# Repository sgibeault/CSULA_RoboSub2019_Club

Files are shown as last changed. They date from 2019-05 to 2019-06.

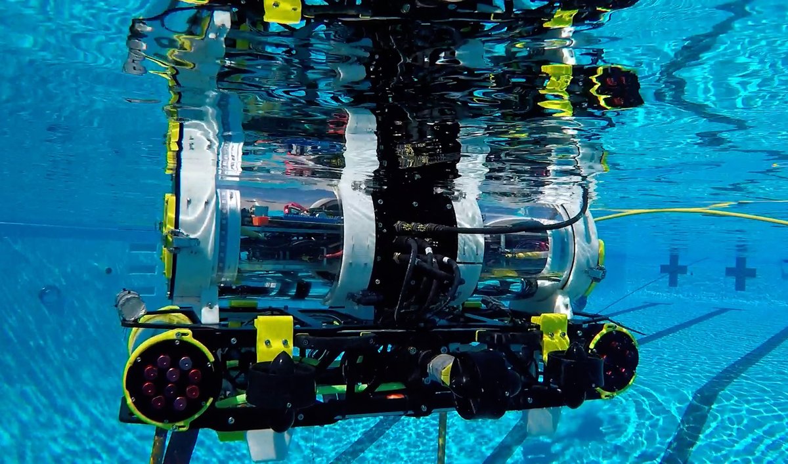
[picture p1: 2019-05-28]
Administrative_Stuff/Photos_Videos/SubPhoto.jpg

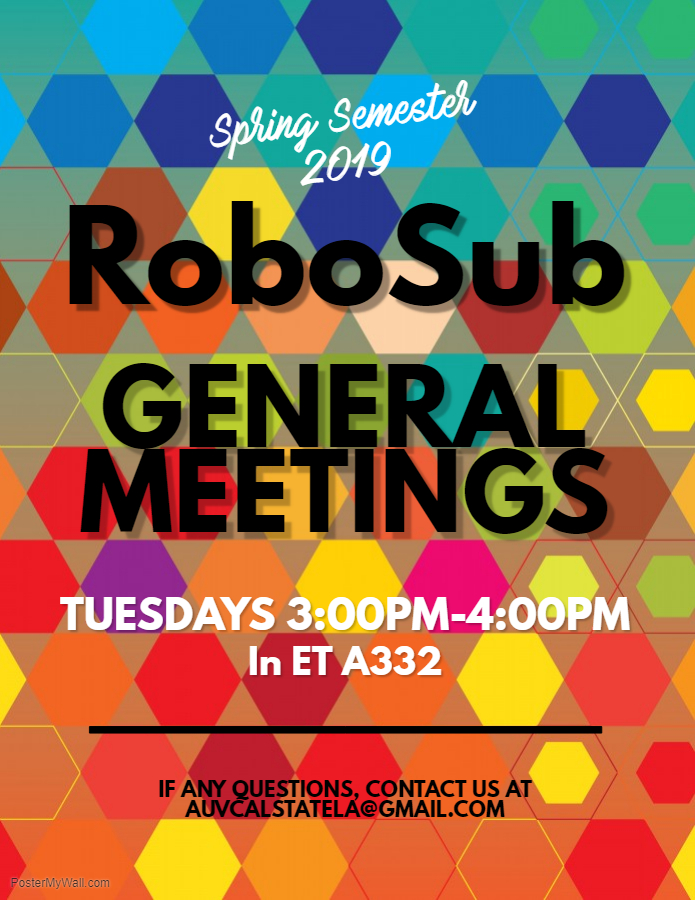
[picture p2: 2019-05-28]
Administrative_Stuff/New_Members/General_Meeting_Stuff/Spring2019GenMeetingFlyer.png

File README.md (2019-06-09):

# CSULA_RoboSub2019_Club
Files for the CSULA RoboSub 2019 club submarine. Her name is M4G1K4RP. 

Sidra's tasks for this week (6/10/19):
- Test barometer in yellow tub in the lab (Tuesday)
- Solder battery connectors and see if we could use the longer tether for next testing (Tuesday)
- Fix library errors with uploading Arduino code over SSH, test this with motherboard on sub (Tuesday)
- Test cameras with CV alg (Wednesday)
- Start working with CV algorithm, set up a plan for training CV -- this means all ROS interfacing between the navigation system and computer vision system should be planned out (Wednesday)
- Install a camera temporarily (Friday)
- Test primitive interface, get a CV system that functions -- doesn't have to detect anything perfectly, just try to get something that works (Friday)

Joseph/Alfonso's tasks for this week (6/10/19):
- Shelving unit laser cut and installed (by Saturday)
- Thruster mounts (by Saturday)

**We will decide on Saturday what the next tasks will be**

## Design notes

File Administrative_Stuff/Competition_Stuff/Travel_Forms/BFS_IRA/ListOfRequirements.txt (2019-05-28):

At Least 14 Days Before:
- Request for Travel
- Breakdown of Expenses
- Class release
- General release for each member
- Emergency contact info for each member
- Lodging exception form 
  + reason why we chose the hotel if over 275/night
- Additional documents/brochure/info
- Fill out this thing: https://na2.docusign.net/Member/PowerFormSigning.aspx?PowerFormId=4b7340e0-2e3a-49a3-bc6e-6d9e34c49fc2

After: 
- Travel expense claim

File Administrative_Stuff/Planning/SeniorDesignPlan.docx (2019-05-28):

# ME RoboSub Senior Design Schedule

Goals

The main goals for the 2019 RoboSub project are to reduce the weight and size of the sub’s frame and reduce the amount of space taken up by the electronics system. Last year’s project will be used as a reference for these tasks. The weight of last year’s submarine is 98lbs, and we hope to reduce this to less than 85lbs. For the electronics system, we want a custom made dc-dc converter circuit board that has multiple voltage outputs, a custom servo control board, and a hydrophone control board. We hope that everyone will be dedicated to the project and will choose to attend the competition with the team next July!

Fall Semester

Week 3 (Sep 2-8) Learn about the project

Week 4 (Sep 9-15) Learn about the project

Week 5 (Sep 16-22) Plan frame/hull weight reduction, review old circuit boards and electrical interface

Week 6 (Sep 23-29) Plan frame/hull weight reduction, research sensors

Week 7 (Sep 30-Oct 6) Plan frame/hull weight reduction, work on power distribution board schematic

Week 8 (Oct 7-13) Begin SolidWorks sub model, work on power distribution board schematic

Week 9 (Oct 14-20) SolidWorks sub design, power distribution board CAD/breadboard testing

Week 10 (Oct 21-27) SolidWorks sub design, work on servo board schematic

Week 11 (Oct 28-Nov 3) SolidWorks sub design, work on servo board schematic

Week 12 (Nov 4-10) Finish sub CAD model, servo board CAD/breadboard testing

Week 13 (Nov 11-17) Buy materials, research manufacturing costs, research electronic components/prices

Week 14 (Nov 25-Dec 1) Send out parts to be manufactured, order boards and components

Week 15 (Dec 2-8) Study :)

Spring Semester

Week 1 (Jan 20-26) Weight calculations

Week 2 (Jan 27-Feb 2) Weight calculations

Week 3 (Feb 3-9) Assembly

Week 4 (Feb 10-16) Assembly

Week 5 (Feb 17-23) Component placement

Week 6 (Feb 24-Mar 2) Component placement

Week 7 (Mar 3-9) Documentation

Week 8 (Mar 10-16) Adjustments

Week 9 (Mar 17-23) Adjustments

Week 10 (Mar 24-30) Adjustments

Week 11 (Apr 7-13) Buoyancy testing/adjusting

Week 12 (Apr 14-20) Buoyancy testing/adjusting

Week 13 (Apr 21-27) Pool testing

Week 14 (Apr 28-May 4) Pool testing

Week 15 (May 5-11) Study :)

Spring Semester

Week 1 (Jan 20-26) Wire thickness calculations

Week 2 (Jan 27-Feb 2) Hydrophone board schematic

Week 3 (Feb 3-9) Hydrophone board schematic

Week 4 (Feb 10-16) Hydrophone board CAD/breadboard testing

Week 5 (Feb 17-23) Order hydrophone board & components, soldering

Week 6 (Feb 24-Mar 2) Soldering components

Week 7 (Mar 3-9) Wiring the electrical interface

Week 8 (Mar 10-16) Wiring the electrical interface

Week 9 (Mar 17-23) Waterproofing

Week 10 (Mar 24-30) Waterproofing

Week 11 (Apr 7-13) Connectors

Week 12 (Apr 14-20) Connectors

Week 13 (Apr 21-27) Pool testing

Week 14 (Apr 28-May 4) Pool testing

Week 15 (May 5-11) Study :)

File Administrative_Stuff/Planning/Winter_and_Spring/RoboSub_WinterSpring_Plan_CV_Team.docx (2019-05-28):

# Computer Vision Team Schedule

Goals

The goal of the computer vision team is to create a system using ROS and OpenCV that can detect objects and colors under the water using a camera module, go pro, or webcam (whichever is easiest). This system will provide the signals to the Arduino controlling the thruster movement and navigation.

Winter

Week 1 (Dec 17-23) Finish learning about ROS, practice programming packages, nodes, messages, services etc. Create architecture.

Week 2 (Dec 24-30) Work on CV system programming, learn how to use OpenCV. Research options, finalize architecture

Week 3 (Dec 31-Jan 6) Work on programming

Week 4 (Jan 7-13) Work on programming

Week 5 (Jan 14-20) Work on programming

Spring

Week 1 (Jan 21-27) Test system with simple object detection, make changes as needed

Week 2 (Jan 28-Feb 3) Continue testing and bug fixing

Week 3 (Feb 4-10) CV system ready for pool testing.

Week 4 (Feb 11-17) Work on interfacing navigation system

Week 5 (Feb 18-24) Have a test-ready vehicle (assemble everything)

Week 6 (Feb 25-Mar 3) Finish interfacing navigation system

Week 7 (Mar 4-10) Second pool test: image collecting

Week 8 (Mar 11-17) Third pool test: image collecting

Week 9 (Mar 18-24) Fourth pool test: image collecting and CV testing

Week 10 (Mar 25-31) Fifth pool test: image collecting and CV testing

Spring Break (Apr 1-7) Finish CV integration with weapons systems. Sixth pool test: weapons systems

Week 11 (Apr 8-14) Testing

Week 12 (Apr 15-21) Testing

Week 13 (Apr 22-28) Testing

Week 14 (Apr 29-May 5) Testing

Week 15 (May 6-12) Testing

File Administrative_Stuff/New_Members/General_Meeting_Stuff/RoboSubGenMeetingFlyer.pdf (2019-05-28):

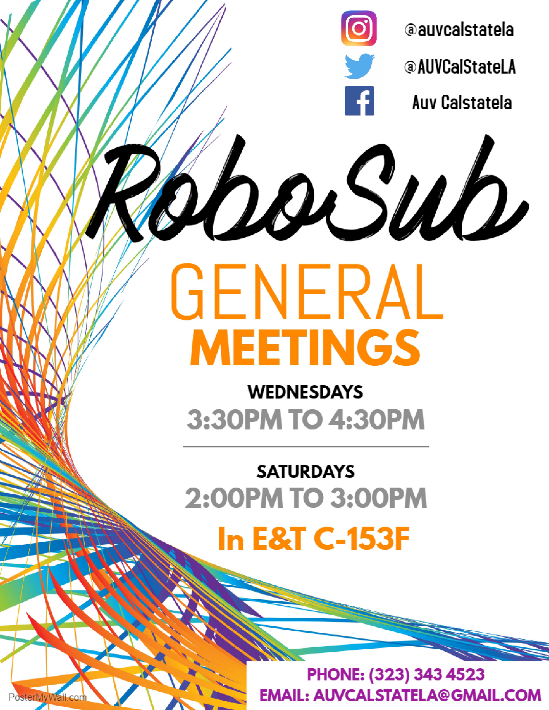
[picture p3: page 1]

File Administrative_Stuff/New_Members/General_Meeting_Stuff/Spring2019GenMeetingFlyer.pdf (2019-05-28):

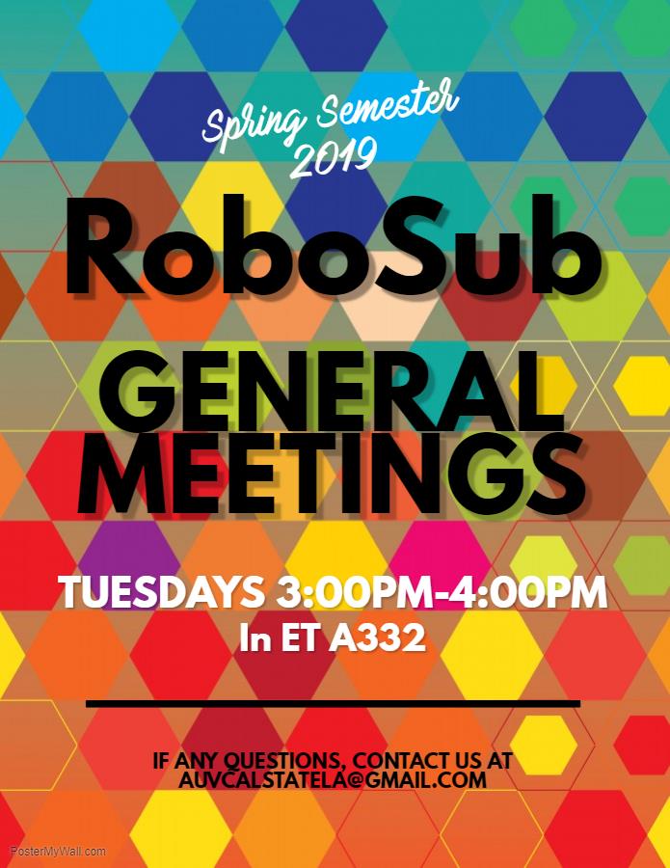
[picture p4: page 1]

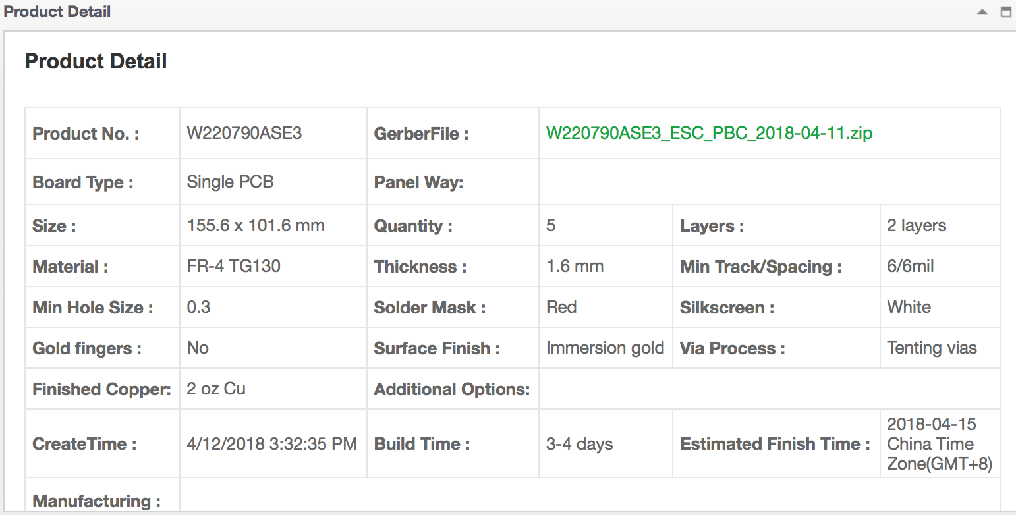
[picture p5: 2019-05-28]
Electrical/EagleCAD_Thruster_Board/Screen Shot 2018-04-15 at 4.21.25 PM.png

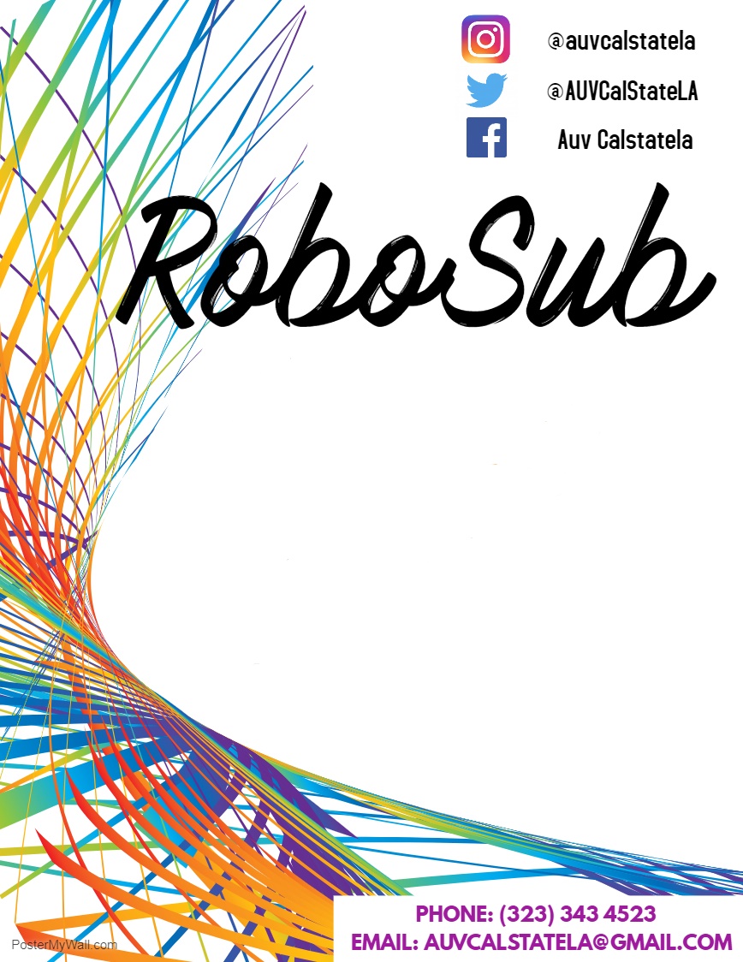
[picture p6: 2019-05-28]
Administrative_Stuff/New_Members/General_Meeting_Stuff/InkedRoboSubBlankFlyer.jpg

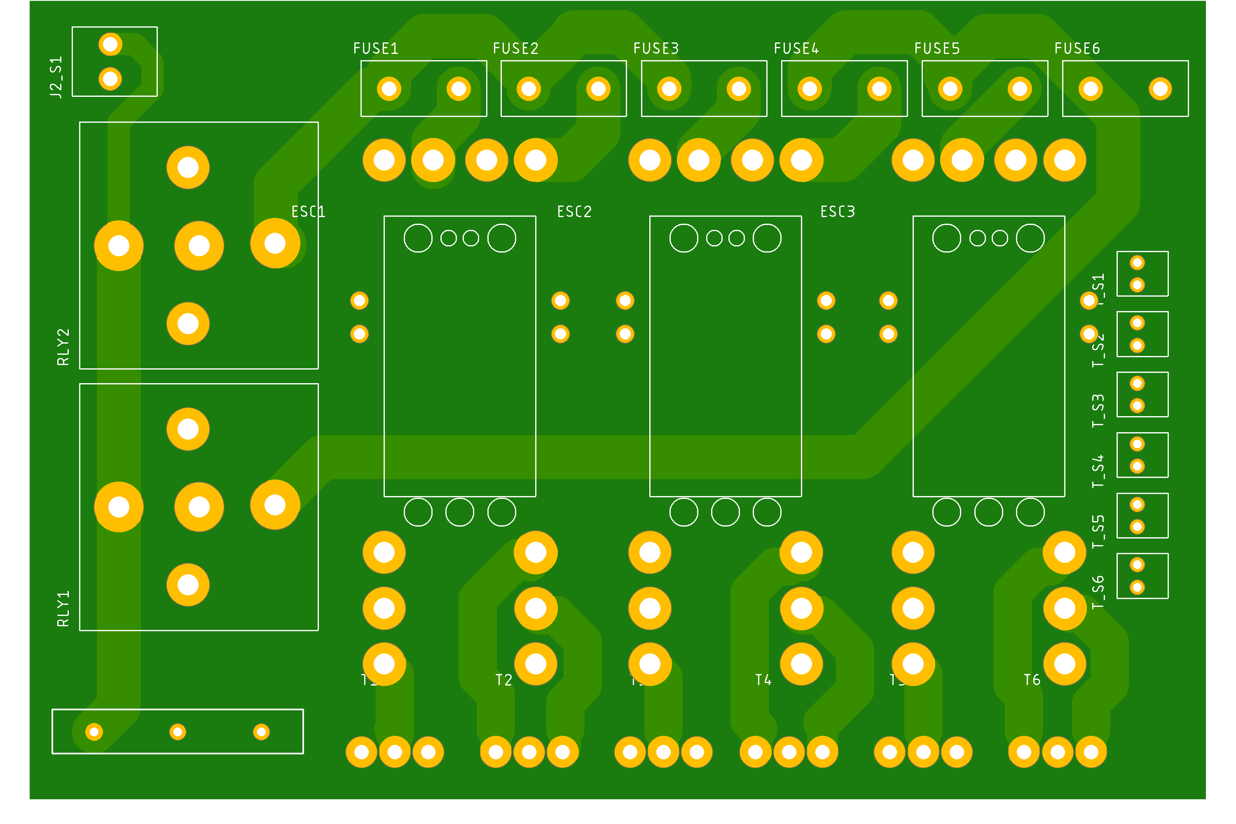
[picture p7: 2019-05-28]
Electrical/EagleCAD_Thruster_Board/TBoard_2019.png

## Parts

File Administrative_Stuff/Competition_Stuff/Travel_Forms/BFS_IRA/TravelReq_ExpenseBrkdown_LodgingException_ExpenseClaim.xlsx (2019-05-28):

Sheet: Breakdown of Expenses
 | Dates | Dates | Dates | Dates | Dates
Description |  |  |  |  |  | Total
Registration/business expense | $0.00 | $0.00 | $0.00 | $0.00 | $0.00 | $0.00
Hotel/lodging (Max. $275.00 before taxes) | $0.00 | $0.00 | $0.00 | $0.00 | $0.00 | $0.00
Airfare/transportation | $0.00 | $0.00 | $0.00 | $0.00 | $0.00 | $0.00
Meals up to $55.00 with overnight stay | $0.00 | $0.00 | $0.00 | $0.00 | $0.00 | $0.00
Incidentals (up to $7.00) | $0.00 | $0.00 | $0.00 | $0.00 | $0.00 | $0.00
Mileage (54.5 cents per mile) | $20.00 | $0.00 | $0.00 | $0.00 | $0.00 | $20.00
Rental Car/Taxi/Shuttle/transportation | $0.00 | $0.00 | $0.00 | $0.00 | $0.00 | $0.00
Gas/business expense | $0.00 | $0.00 | $0.00 | $0.00 | $0.00 | $0.00
Phone/Fax/business expense | $0.00 | $0.00 | $0.00 | $0.00 | $0.00 | $0.00
Parking | $0.00 | $0.00 | $0.00 | $0.00 | $0.00 | $0.00
Relocation/Moving Expense | $0.00 | $0.00 | $0.00 | $0.00 | $0.00 | $0.00
 | $20.00 | $0.00 | $0.00 | $0.00 | $0.00 | $20.00
Traveler:
Purpose:
Shuttle:

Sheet: Travel Form
 | Business Financial Services
Request for Travel
I. GENERAL INFORMATION: |  |  |  |  | SHADED AREAS FOR ACCOUNTING USE ONLY
Last Name, First Name |  |  |  |  |  | Initials |  | Employee ID#
Department |  |  |  |  | Ext. | Destination of Trip (City\State\Country (Intl Travel)
Departure to Destination |  |  | Date | Time |  | Return from |  | Date |  | Time
 |  |  |  |  |  | Destination
 | Emergency Contact |  | ___________________________________________________________________
Emergency Phone Number/Email |  |  | ___________________________________________________________________
Home/Remit Address
Personnel Classification/Type of Travel (Check one box in each column):
 | Employee Category |  |  |  |  | Type of Travel |  |  |  |  |  | 606802 Travel - Mileage
 |  | A |  |  |  | A |  |  |  |  |  | 606802 Travel - Mileage
 |  | B |  |  |  | B
 |  | C |  |  |  | C
 |  | D |  |  |  | D
 |  | E |  |  |  | E
 |  | F |  |  |  | F |  |  |  |  |  | 606800 Travel - in State
 |  |  |  |  |  | G
 |  |  |  |  |  |  |  |  |  |  |  | 606801 Travel - in State Faculty
II. FINANCIAL INFORMATION |  |  |  |  |  |  |  |  |  |  |  | 606820 Travel - out of State
Account |  |  | Fund-Department-Program-Project |  |  |  |  | Amount |  |  |  | 606821 Travel - out of State Faculty
 |  |  |  |  |  |  |  | $0.00 |  |  |  | 660890 Recruitment and Emp Relocation
 |  |  |  |  |  |  |  | $20.00 |  |  |  | 660891 Faculty Recruitment
 |  |  |  |  |  |  |  | $0.00 |  |  |  | 660977 Official Guest
 |  |  |  |  |  |  |  | $0.00 |  |  |  | 613001 Contractual services
 |  |  |  |  |  |  |  | $20.00 | ** Total Request |  |  | 660850 Guest artists
 |  |  |  |  |  |  |  |  |  |  |  | 606807 Travel Overtime meal Reimb
 | ** Total Request should include all expenses. In the event expenses are more than original request, please |  |  |  |  |  |  |  |  |  |  | 606806 Team Travel - in State
 | submit a memo from department to increase amount along with travel claim. |  |  |  |  |  |  |  |  |  |  | 606811 Team Travel - out of State
 |  |  |  |  |  |  |  |  |  |  |  | 660972 Honorarium
Signature of Traveling Requestor |  |  |  |  | Date |  | Signature of Authorized Personnel |  |  |  | Date | 660009 Specialized Training
International Approval: |  |  |  |  |  |  |  |  |  |  |  | 606802 Travel - Mileage
Vice President |  |  |  |  | Date |  | President |  |  |  | Date | 606803 Travel - Mileage Faculty
Per Administrative Procedure 208, approval is required when reimbursement for moving and relocation expenses exceeds $5,000/$10,000.
Vice President |  |  |  |  | Date |  | Vice President for Administration and CFO |  |  |  | Date | 606803 Travel - Mileage Faculty
III. REQUEST FOR TRAVEL ADVANCE
TO: | Business Financial Services: Please issue me a travel advance check in the amount of :
 | Name of Company |  |  |  | Amount | for the above trip. |  |  |  | Date
 |  |  |  |  |  | I need the advance by:
 | Authorization by Employee: |  |  |  | This is to authorize the University to deduct from my paycheck any
 |  |  |  |  | outstanding travel advance after 30 calendar days from return of trip.
 |  |  |  |  |  | Signature of Employee Requesting Advance
 | Date:
 | Form Prepared By:
 |  |  |  |  | Purpose of Trip:
Forms Required:
Form 204 |  |  |  | Remarks:
Breakdown of Expenses
Form 262
Form 261 |  |  |  | Advance Check |  | Number |  |  | Date |  | $ Amount
____________ Other |  | Revised: January 2016 |  | Information

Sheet: Travel Check List
Request for Travel – Advances (submit copy to Business Financial Services)
Checklist Items | Yes | Not Required | Comments | BFS use only
Breakdown of Expenses Spreadsheet
Supporting Documents - Agenda, Brochure, Invitation
Invoice/Confirmation for Hotel, Registration, Airfare and/or Car Rental (requires 204 form if new vendor)
Receipt for Prepaid Expense
CPO (cash posting order) Memo/Registration
International with Advance
International Travel – Provost and President approval
High Hazard Questionnaire (if applicable)
Request for Travel – Moving & Relocation (submit copy to Business Financial Services)
Dates of the Move
Approval
* Dean ‘s approval for $5k or less
* Vice President’s approval for less than $10k
* VPAF/CFO’s approval for $10k and over
Moving Company Estimate, 204 form, Certification of Insurance (if applicable)
Request for Travel – Off Campus Event (submit copy to Business Financial Services)
Waiver from Golden Eagle
Certificate of Insurance for Venue
Agreement |  |  | Approved by Procurement only
Invoice/Estimate
Hospitality Form
Travel Expense Claim (include the original Request for Travel)
Checklist Items | Yes | Not Required | Comments | BFS use only
Written on Claim
Time of Departure and Return
Purpose of Trip
Work Hours
Private Vehicle License Number
Supporting Documentation
Agenda, Brochure, Invitation
Transportation receipt (air, rental, taxi, bus, shuttle)
Lodging Receipt
Lodging Exception (Approved prior to trip)
Registration Receipt
Parking Expense Receipt
Map/Proof of Mileage
Receipts for any expenses $25.00 and over
Approval signature for claim reimbursement that is over the Request for Travel amount
Form 261 (Authorization to Use Privately Owned Vehicle on State Business) |  |  | Attach if not previously submitted for the current fiscal year
Group Meals - Hospitality Form & List of Participants
Moving & Relocation – Receipts for out of pocket expenses
Revised: November 7, 2014

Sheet: Travel Claim
State of California
TRAVEL EXPENSE CLAIM |  |  |  | See Instructions and "Privacy
STD. 262 (REV. 6/93) |  |  |  | Statement On Reverse Side |  |  |  |  |  |  | Page ________ of _______Pages
CLAIMANT'S NAME |  |  |  |  |  |  |  |  |  |  | DEPARTMENT
POSITION |  |  |  | CB/ID NUMBER |  | DIVISION OR BUREAU |  |  |  |  |  |  | I NDEX NUMBER
 |  |  |  |  |  | CSU Los Angeles
RESIDENCE ADDRESS* |  |  |  |  |  | HEADQUARTERS ADDRESS |  |  |  |  |  |  | TELEPHONE NUMBER
 |  |  |  |  |  | 5151 STATE UNIVERSITY DRIVE
CITY |  |  | STATE | ZIP CODE |  | CITY |  |  |  |  | STATE |  |  | ZIP CODE
 |  |  |  |  |  | LOS ANGELES |  |  |  |  | CA |  |  | 90032
(1) MONTH/YEAR |  | (3) | (4) | (5) | MEALS |  | (6) | (7) |  | TRANSPORTATION |  |  | (8) | (9)
 |  |  |  |  |  | O.T.. L/T |  | (A) | (B) | (C) |  | (D)
 |  | LOCATION |  |  |  | N/C, RELOC. | INCIDEN- |  |  | CARFARE, | PRIVATE CAR USE |  | BUSINESS | TOTAL
(2) |  | WHERE EXPENSES | LODGING | BREAK- |  | OR | TALS | COST OF | TYPE | TOLLS, |  |  | EXPENSE | EXPENSES
DATE | TIME | WERE INCURRED |  | FAST | LUNCH | DINNER |  | TRANS. | USED | PARKING | MILES | AMOUNT |  | FOR DAY
 |  |  |  |  |  |  |  |  |  |  |  |  |  | 0.00
 |  |  |  |  |  |  |  |  |  |  |  |  |  | 0.00
 |  |  |  |  |  |  |  |  |  |  |  |  |  | 0.00
 |  |  |  |  |  |  |  |  |  |  |  |  |  | 0.00
 |  |  |  |  |  |  |  |  |  |  |  |  |  | 0.00
 |  |  |  |  |  |  |  |  |  |  |  |  |  | 0.00
 |  |  |  |  |  |  |  |  |  |  |  |  |  | 0.00
 |  |  |  |  |  |  |  |  |  |  |  |  |  | 0.00
 |  |  |  |  |  |  |  |  |  |  |  |  |  | 0.00
 |  |  |  |  |  |  |  |  |  |  |  |  |  | 0.00
 |  |  |  |  |  |  |  |  |  |  |  |  |  | 0.00
 |  |  |  |  |  |  |  |  |  |  |  |  | CT
 |  |  |  |  |  |  |  |  |  |  |  |  | Advances
 |  |  |  |  |  |  |  |  |  |  |  |  | Bal. | 0.00
(10)
 | SUBTOTALS |  | 0.00 | 0.00 | 0.00 | 0.00 | 0.00 | 0.00 |  | 0.00 |  | 0.00 | 0.00 | 0.00
COLUMNS CODE (ACCTG. USE ONLY)
 | CLAIM TOTAL |  |  |  |  |  |  |  |  |  |  |  | $ | 0.00
(11) PURPOSE OF TRIP, REMARKS AND DETAILS (Attach Receipts/vouchers when required) |  |  |  |  |  |  |  |  |  |  |  | (12) NORMAL WORK HOURS
 |  |  |  |  |  |  |  |  |  |  |  | (13) PRIVATE VEHICLE LICENSE NUMBER
Advances:
 |  |  |  |  |  |  |  |  |  |  |  | (14) MILEAGE RATE CLAIMED
 |  |  |  |  |  |  |  |  |  |  |  |  | 54.5
Please reimburse actual expenses; instead of amount on Request. ________________________________________________ |  |  |  |  |  |  |  |  |  |  |  | AGENCYACCOUNTING OFFICE
AB 1887 Travel Exemption (submit justification) |  |  |  |  |  |  |  |  |  |  |  | USE ONLY
 | Account Number: |  |  |  |  |  |  |  |  |  |  | PAID BY REVOLVING FUND CHECK NUMBER
(15) | I HEREBY CERTIFY That the above is a true statement of the travel expenses incurred by me in accordance with DPA rules in the service of the State
 | of California. If a privately owned vehicle was used, and if mileage rates exceed the minimum rate, I certify that the cost of operating the vehicle was equal
 | to or greater than the rate claimed, and that I have met the requirements as presceibed by SAM Sections 0750, 0751, 0752, 0753 and 0754 pertaining to
 | vehicle safety and seat belt usage.
CLAIMANT'S SIGNATURE |  |  |  | DATE |  | (16) SIGNATURE OF OFFICER APPROVING TRAVEL AND PAYMENT |  |  |  |  |  |  | DATE
(17) SPECIAL EXPENSE AUTHORIZATION - SIGNATURE and TITLE (See Item 17on Reverse) |  |  |  |  |  |  |  |  |  |  |  |  | DATE

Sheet: Intl High Hazard
TRAVELER'S INFORMATION FOR HIGH HAZARD AREAS/COUNTRIES
Last Name, First Name |  |  | Employee Type:
*If traveler is a student, was an Informed Consent/Waiver executed? (YES/NO)
**If traveler is a minor, was an Informed Consent/Waiver executed by a parent or guardian? (YES/NO)
Is This Trip Sponsored by the University? (YES/NO)
Destination Information (Include all Regions, Cities and Towns) |  |  |  |  | From | To
Do any of your destinations (including layovers) appear on the following lists? (YES/NO)
1. High Hazardous (http://www.calstate.edu/risk_management/documents/CSURMA_HighHazardList.pdf)
2 US State Department Travel Warning (http://www.travel.state.gov)
If less than 5 days’ notice, provide reason for late request below:
Purpose Of Travel: |  | *Other (describe):
Value to campus or CSU as it relates to University business:
For Group Trips, please list ALL travelers:
Campus Coordinator Name:
Campus Coordinator Phone:
Employee Traveling? (YES/NO) |  |  | If YES, then please list names below:
Employee Name: |  | Employee Name:
Employee Name: |  | Employee Name:
Student Traveling? (YES/NO) |  |  | Total # of Students Traveling:
Student Name: |  | Student Name:
Student Name: |  | Student Name:
Other Participants? (YES/NO) |  |  | If YES, then please list names below:
Participant Name: |  | Participant Name:
Participant Name: |  | Participant Name:
TRANSPORTATION TO/FROM THE FOREIGN DESTINATION:
Airports being used: List All Airports
Transportation To/From the Foreign Destination (check all that apply):
Air | Rental Car |  | Bus |  | Other*:
Motor Vehicle | Hired Car |  | *If Other (please specify below):
Ship/Boat | Hired Driver
Contact Information While on Travel
Traveler Phone #: |  |  | Type:
Emergency Contact:
Emergency Contact Phone: |  |  | Contact Relationship:
LODING WHILE ON TRAVEL (provide information for all lodging locations):
Lodging Name:
Lodging Address:
Lodging Phone:
Lodging Name:
Lodging Address:
Lodging Phone:
SITE VISIT DETAILS |  |  |  | Type:
Site Location:
Site Point of Contact:
TRANSPORTATION TO/FROM LODGING AND SITE LOCATION
Airports being used: List All Airports
Transportation To/From Lodging and Site Location (check all that apply):
Air | Rental Car |  | Bus |  | Other*:
Motor Vehicle | Hired Car |  | *If Other (please specify below):
Ship/Boat | Hired Driver
Traveler Enrolled in US State Department STEP? (Safe Traveler Enrollment Program)
Additional Security Concerns?

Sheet: Lodging Exception
 |  | Request for Exception Lodging (maximum $275.00 per night)
 |  | TRAVEL – Business Financial Services
 |  | Administration 514 * (323) 343-3550
Date: |  |  |  | Department: |  |  | Extension:
Traveler’s Information:
Last Name: |  |  |  |  |  | First Name:
Destination of Trip: |  |  |  |  |  | Daily Rate (Before Taxes):
Departure Date: |  |  |  |  |  | Return Date:
Justification for Exception:
Vice President Exception Approval:
Print Name |  |  |  |  | Signature |  |  | Date
VPA & CFO Review and Recommendation
Approved | o | Denied | o |  | Signature: |  |  | Date:
 |  |  |  |  | Lisa Chavez, VPA & CFO, Administration & Finance
FOR TRAVEL DEPARTMENT ONLY:

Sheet: Routing Forms
 | TRAVEL – Business Financial Services
Submission of Forms
Prior to Trip:
Request for Travel Form and the Breakdown of Expenses Spreadsheet to Business Financial Services
a. Submit the approved Request for Travel and Breakdown of Expenses (Advances - two weeks prior to trip)
b. International Travel: submit approved Request for Travel and Breakdown of Exenses two months prior to trip
Advances consist of: Registration Fees, Prepaid Expenses, Airfare, Hotel, CPO (Cash Posting Order) and Rental Car.
International Travel Questionnaire for High Hazard Area
a. Complete form and send it along with a copy the approved Request for Travel and Breakdown of Expenses Spreadsheet
b. Dean's Office will forward the form to the Provost for approval
c. Provost Office will forward form to the President's Office
d. President's Office will return form to the Provost Office
Lodging Exception for $195.00 maximum excluding taxes
a. Complete form and send it along with a copy of the approved Request for Travel and Breakdown of Expenses Spreadsheet
b. Vice President Office needs to forward the form to Lisa Chavez for authorization
c. VPA & CFO will forward the form to Business Financial Services
Trip Completed:
Travel Expense Claim
a. Must be submitted to the campus Business Financial services office within 30 days of the end of the trip.
b. Original Request for Travel Form
c. Receipts and supporting documentation
d. Travel Check List

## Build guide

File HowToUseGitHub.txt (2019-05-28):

/* 
 * This document was written by Sidra Gibeault
 * Last updated on 5/28/19
 * This file is property of the CSULA RoboSub team
*/

Hi fellow CalStateLA AUV members -
in case you are unfamiliar with GitHub, here's all you need to know to navigate this repository (file database), download files, upload files, delete files, and delete folders. 

The link to the 2019 RoboSub GitHub repository is: https://github.com/sgibeault/CSULA_RoboSub2019_Club
To be granted editing privileges, please send Sidra your GitHub username or the email address linked to your account. She will grant editing privileges so you may upload and edit files in the repository. 

*Navigating the repository and downloading files*

You will notice many folders labelled Electrical, Computer Science, Mechanical, Associative_Stuff, etc. If you click on any of these folders, just like on your computer desktop, it will show you the files and folders inside. You will notice that your "path" is listed on the top, with the main folder being called CSULA_RoboSub2019_Club. If you wish to go back to a previous folder quickly, you can click on it in this path. Now, to download files from a GitHub repository, you must download the folder they are in. Go to the folder that has the file you want to download in it, and scroll down until you see on the far right of your screen a green button that says "Clone or download". If you click this button, it gives you the option to 'Open in Desktop' or 'Download ZIP'. Click 'Download ZIP' and extract the folder on your computer. You have now downloaded the folder and can view and edit the files on your local computer. 

*Uploading files*

To upload files to a GitHub repository, you can simply click the "Upload files" button. This will allow you to find the files on your local machine and transfer them to the online repository. Make sure you click this button inside the correct folder. 

*Deleting files*

Say you uploaded the wrong files, or you want to update an old version of a file. To delete a file from a GitHub repository, simply navigate to the folder that has the file in it, click on the file, and find the small trash can icon on the right side of your screen by scrolling down. Click this icon, then scroll down and press the green button that says "Commit changes". This will confirm that you want to delete the file. After you complete these steps, the file will be deleted. 

*Deleting a folder*

Say you upload a folder accidentally, and you wish to remove it from the repository. Unfortunately, there is no simple way to delete a folder in a repository. To do so, you must delete every file inside the folder. Once this is done, the folder will disappear from the repository.

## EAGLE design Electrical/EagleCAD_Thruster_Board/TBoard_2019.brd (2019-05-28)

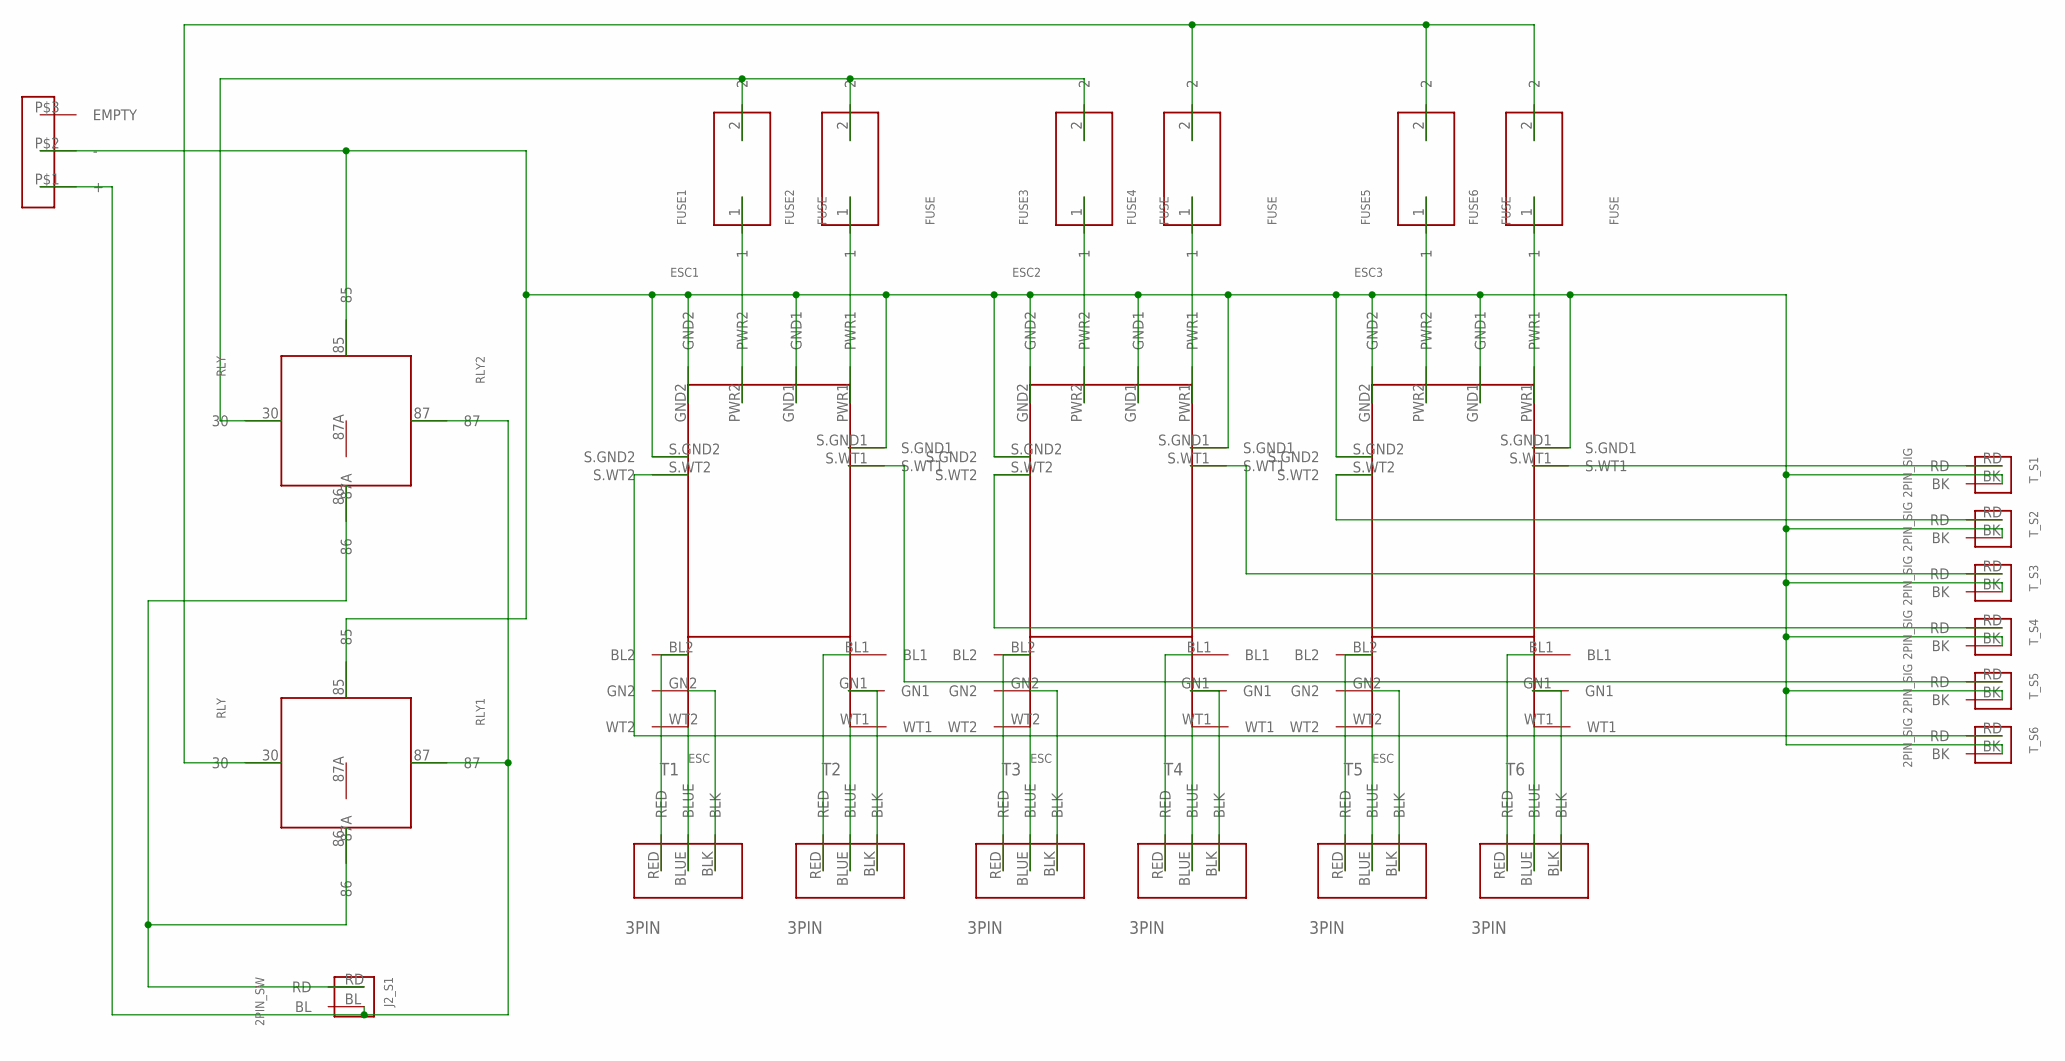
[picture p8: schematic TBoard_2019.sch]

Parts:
ESC1, ESC2, ESC3: ESC
FUSE1, FUSE2, FUSE3, FUSE4, FUSE5, FUSE6: FUSE
J2_S1: 2PIN_SW
RLY1, RLY2: RLY
T1, T2, T3, T4, T5, T6: 3PIN
T_S1, T_S2, T_S3, T_S4, T_S5, T_S6: 2PIN_SIG
U$1: TERMINAL

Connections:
unnamed: ESC1.GND1, ESC1.GND2, ESC1.S.GND1, ESC1.S.GND2, ESC2.GND1, ESC2.GND2, ESC2.S.GND1, ESC2.S.GND2, ESC3.GND1, ESC3.GND2, ESC3.S.GND1, ESC3.S.GND2, RLY1.85, RLY2.85, T_S1.BK, T_S2.BK, T_S3.BK, T_S4.BK, T_S5.BK, T_S6.BK, U$1.P$2 (-)
unnamed: J2_S1.BL, RLY1.87, RLY2.87, U$1.P$1 (+)
unnamed: J2_S1.RD, RLY1.86, RLY2.86
unnamed: ESC1.BL2, T1.RED
unnamed: ESC1.GN2, T1.BLK
unnamed: ESC1.WT2, T1.BLUE
unnamed: ESC1.BL1, T2.RED
unnamed: ESC1.GN1, T2.BLK
unnamed: ESC1.WT1, T2.BLUE
unnamed: ESC2.BL2, T3.RED
unnamed: ESC2.GN2, T3.BLK
unnamed: ESC2.WT2, T3.BLUE
unnamed: ESC2.BL1, T4.RED
unnamed: ESC2.GN1, T4.BLK
unnamed: ESC2.WT1, T4.BLUE
unnamed: ESC3.BL2, T5.RED
unnamed: ESC3.GN2, T5.BLK
unnamed: ESC3.WT2, T5.BLUE
unnamed: ESC3.BL1, T6.RED
unnamed: ESC3.GN1, T6.BLK
unnamed: ESC3.WT1, T6.BLUE
unnamed: FUSE4.2, FUSE5.2, FUSE6.2, RLY1.30
unnamed: ESC1.PWR2, FUSE1.1
unnamed: ESC1.PWR1, FUSE2.1
unnamed: ESC2.PWR2, FUSE3.1
unnamed: ESC2.PWR1, FUSE4.1
unnamed: ESC3.PWR2, FUSE5.1
unnamed: ESC3.PWR1, FUSE6.1
unnamed: ESC3.S.WT1, T_S1.RD
unnamed: ESC3.S.WT2, T_S2.RD
unnamed: ESC2.S.WT1, T_S3.RD
unnamed: ESC2.S.WT2, T_S4.RD
unnamed: ESC1.S.WT1, T_S5.RD
unnamed: ESC1.S.WT2, T_S6.RD
unnamed: FUSE1.2, FUSE2.2, FUSE3.2, RLY2.30

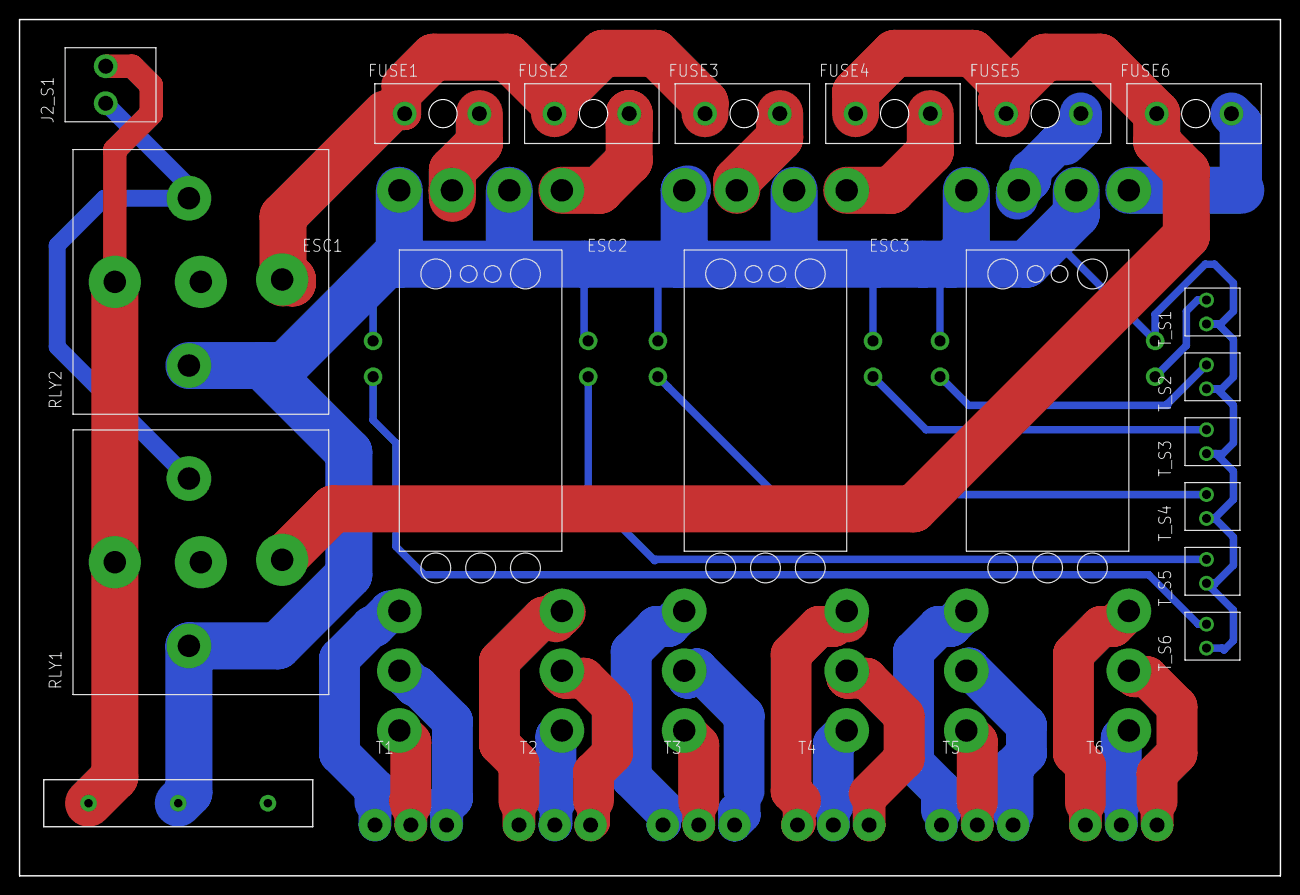
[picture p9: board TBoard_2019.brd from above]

Board: 2 copper layers, 134.0 x 91.0 mm, 25 parts (0 on the bottom side), 35 nets.

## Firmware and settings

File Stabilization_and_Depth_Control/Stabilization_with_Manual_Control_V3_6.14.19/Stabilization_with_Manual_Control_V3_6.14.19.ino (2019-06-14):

/* Robosub 2018-2019 Stabilization Code 
 *  Current Revision: 060819
 *  Joseph Daniel Iorio
 *  Sidra Gibeault
 *  
 *  -- Revision log --
 *  040619: Joseph - PID gains tuned during 04/06/19 pool testing. Depth control implemented. 
 *  052219: Joseph - Integrated new IMU (Adafrtuit/Bosch BNO055)
 *  060119: Sidra - Added manual control code for dynamic ROV movement
 *  061419: Sidra - Fixed issue with barometer code
 *  
 */


#include <Wire.h>
#include <Servo.h>
#include "MS5837.h"
#include <Adafruit_BNO055.h>
#define BNO055_SAMPLERATE_DELAY_MS (100)

Adafruit_BNO055 bno = Adafruit_BNO055();

int control = 0;

MS5837 sensor;

Servo thruster_frontright;
Servo thruster_frontleft;
Servo thruster_backright;
Servo thruster_backleft;
Servo thruster_sideright;
Servo thruster_sideleft;

float elapsedTime, time, timePrev;
float PIDY, PIDX, PIDZ, pwmFrontRight, pwmFrontLeft, pwmBackRight, pwmBackLeft, pwmSideLeft, pwmSideRight, errorY, errorX, errorZ, previous_errorY, previous_errorX, previous_errorZ, current_depth, PID_depth, depth_error, previous_depth_error;
float pid_pY=0;
float pid_iY=0;
float pid_dY=0;
float pid_pX=0;
float pid_iX=0;
float pid_dX=0;
float pid_pZ=0;
float pid_iZ=0;
float pid_dZ=0;
float pid_p_depth = 0;
float pid_d_depth = 0;
float pid_i_depth = 0;
float y_angle = 0;
float x_angle = 0;
float z_angle = 0;

/////////////////PID GAINS/////////////////
double kp=3.5;// 3.5 WORKED
double ki=0.0000005;// 0 WOKRED
double kd=4;// 4 WORKED
///////////////////////////////////////////////

double throttle=1500; //Motor throttle --> Linearized control about this nominal thruster setting (0 thrust since we don't want thrusters constantly running)
float desired_angle = 0; //Setpoint angle
float desired_depth = 1; //Setpoint depth


void setup() {
  
  Wire.begin(); //begin the wire comunication
  Serial.begin(9600);
  thruster_frontright.attach(5); //attatch the front to pin 3
  thruster_frontleft.attach(6);  //attatch the backthruster to pin 5
  thruster_backright.attach(7); //attach the right thruster to pin 6
  thruster_backleft.attach(9); //attach the left thruster to pin 9
  thruster_sideright.attach(10); // etc.
  thruster_sideleft.attach(11); // etc.
  
  time = millis(); //Time is in miliseconds
  thruster_frontright.writeMicroseconds(1500); 
  thruster_frontleft.writeMicroseconds(1500);
  thruster_backright.writeMicroseconds(1500); 
  thruster_backleft.writeMicroseconds(1500);
  //delay(5000); /* Start up delay */

  /* Initialise the IMU */
  
  if(!bno.begin())
  {
    /* There was a problem detecting the BNO055 ... check your connections */
    Serial.print("Ooops, no BNO055 detected ... Check your wiring or I2C ADDR!");
    while(1);
  }
  bno.setExtCrystalUse(true);

  /* Set up Barometer */

  sensor.init();
  sensor.setModel(MS5837::MS5837_30BA);
  sensor.setFluidDensity(997); // kg/m^3 (freshwater, 1029 for seawater)
   
}//end of setup void

void loop() {

    timePrev = time;  // the previous time is stored before the actual time read
    time = millis();  // actual time read
    elapsedTime = (time - timePrev) / 1000; 

/////////////////////////////I M U/////////////////////////////////////
    
    Wire.beginTransmission(0x28);
    imu::Vector<3> euler = bno.getVector(Adafruit_BNO055::VECTOR_EULER);

    y_angle = euler.y();
    x_angle = euler.z();
    z_angle = euler.x(); //Note: IMU interprets vertical axis as x-axis, but we'll refer to it as z-axis 

/*Calculate error between measured and desired angle*/

errorY =  y_angle - desired_angle;
errorX = x_angle - desired_angle;
errorZ = z_angle - desired_angle;


if (errorZ<-180){
  errorZ+=360;
}
else if (errorZ>180){
  errorZ-=360;
}
    
/* Calculate proportional PID term */

pid_pY = kp*errorY;
pid_pX = kp*errorX;
pid_pZ = kp*errorZ;

/* Calculate the integral PID term, only when error is +/- 10 degrees */

if(-10 <errorY <10)
{
  pid_iY = pid_iY+(ki*errorY);  
}

if(-10 <errorX <10)
{
  pid_iX = pid_iX+(ki*errorX);  
}

/*Calculate derivative PID term */

pid_dY = kd*((errorY - previous_errorY)/elapsedTime);
pid_dX = kd*((errorX - previous_errorX)/elapsedTime);
pid_dZ = kd*((errorZ - previous_errorZ)/elapsedTime);

/*Sum all PID terms */

PIDY = pid_pY + pid_dY;
PIDX = pid_pX + pid_dX;
PIDZ = pid_pZ + pid_dZ;

/*Place bounds on PID terms */

//if(PIDY < -100)
//{
//  PIDY=-100;
//}
//if(PIDY > 100)
//{
//  PIDY=100;
//}
//
//if(PIDX < -100)
//{
//  PIDX=-100;
//}
//if(PIDX > 100)
//{
//  PIDX=100;
//}

/*Calculate PWM signal --> Throttle + PID terms = Motor Mixing Algorithm */

/*
Layout for how the PID terms interact with front/back/left/right thrusters
pwmFront = throttle + PIDX;
pwmBack = throttle - PIDX;
pwmRight = throttle - PIDY;
pwmLeft = throttle + PIDY;
*/

/* Barometer  */

 Wire.beginTransmission(0x76); // begin comm with barometer
 sensor.read(); // get data from barometer
 current_depth = sensor.depth(); // create current depth variable
 depth_error = desired_depth - current_depth; // calculate the error between current depth and desired depth
  //Serial.print("Depth: "); 
  //Serial.print(sensor.depth()); 
  //Serial.println(" m");

/* Barometer PID terms */

pid_p_depth = kp*depth_error;


if(-.01 <depth_error <.01)
{
  pid_i_depth = pid_i_depth+(ki*depth_error);
}

pid_d_depth = kd*((depth_error - previous_depth_error)/elapsedTime);


 
PID_depth = pid_p_depth + pid_d_depth;

/* Motor Mixing Algorithm */

//Front Thrusters
//pwmFrontRight = throttle + PIDX - PIDY + PID_depth;
//pwmFrontLeft = throttle + PIDX + PIDY + PID_depth;

pwmFrontRight = throttle - PIDX + PIDY + PID_depth;
pwmFrontLeft = throttle - PIDX - PIDY + PID_depth;

//Back Thrusters
//pwmBackRight = throttle - PIDX - PIDY + PID_depth;
//pwmBackLeft = throttle - PIDX + PIDY + PID_depth;

pwmBackRight = throttle + PIDX + PIDY + PID_depth;
pwmBackLeft = throttle + PIDX - PIDY + PID_depth;


//Side Thrusters


pwmSideRight = throttle;// + PIDZ;
pwmSideLeft = throttle;// - PIDZ;


/*Place bounds on PWM signal */


//Front
if(pwmFrontRight < 1525)
{
  pwmFrontRight= 1500;
}
if(pwmFrontRight > 1560)
{
  pwmFrontRight=1560;
}

if(pwmFrontLeft < 1525)
{
  pwmFrontLeft= 1500;
}
if(pwmFrontLeft > 1560)
{
  pwmFrontLeft=1560;
}
//Back
if(pwmBackRight < 1525)
{
  pwmBackRight= 1500;
}
if(pwmBackRight > 1560)
{
  pwmBackRight=1560;
}

if(pwmBackLeft < 1525)
{
  pwmBackLeft= 1500;
}
if(pwmBackLeft > 1575)
{
  pwmBackLeft=1560;
}
if(pwmSideRight > 1560)
{
  pwmSideRight=1560;
}
if(pwmSideRight < 1525)
{
  pwmSideRight=1500;
}
if(pwmSideLeft > 1560)
{
  pwmSideLeft=1560;
}
if(pwmSideLeft < 1525)
{
  pwmSideLeft=1500;
}

//////////////////////////////////////////////////////

// CASE STATEMENTS FOR MANUAL CONTROL

  if (Serial.available() > 0) {
                // read the incoming byte:
                control = Serial.read();

                // say what you got:
                if ((control >= 49 && control <=57) || (control >= 97 && control <= 119)){
                Serial.print("I received: ");
                Serial.println(control, DEC);
                }
                else{
                  Serial.println("Invalid key pressed.");
                }
        }

  if ((control <= 57 && control >= 49) || (control <= 119 && control >= 97)) {
     switch(control) {
        case 97: //a : turn left
          thruster_frontright.writeMicroseconds(pwmFrontRight); 
          thruster_frontleft.writeMicroseconds(pwmFrontLeft);
          thruster_backright.writeMicroseconds(pwmBackRight); 
          thruster_backleft.writeMicroseconds(pwmBackLeft);
          thruster_sideright.writeMicroseconds(pwmSideRight-100);
          thruster_sideleft.writeMicroseconds(pwmSideLeft+100);
          break;
        case 115: //s : go backwards
          thruster_frontright.writeMicroseconds(pwmFrontRight); 
          thruster_frontleft.writeMicroseconds(pwmFrontLeft);
          thruster_backright.writeMicroseconds(pwmBackRight); 
          thruster_backleft.writeMicroseconds(pwmBackLeft);
          thruster_sideright.writeMicroseconds(pwmSideRight+100);
          thruster_sideleft.writeMicroseconds(pwmSideLeft+100);
          break;
        case 100: //d : turn right
          thruster_frontright.writeMicroseconds(pwmFrontRight); 
          thruster_frontleft.writeMicroseconds(pwmFrontLeft);
          thruster_backright.writeMicroseconds(pwmBackRight); 
          thruster_backleft.writeMicroseconds(pwmBackLeft);
          thruster_sideright.writeMicroseconds(pwmSideRight+100);
          thruster_sideleft.writeMicroseconds(pwmSideLeft-100);
          break;
        case 119: //w : go forward
          thruster_frontright.writeMicroseconds(pwmFrontRight); 
          thruster_frontleft.writeMicroseconds(pwmFrontLeft);
          thruster_backright.writeMicroseconds(pwmBackRight); 
          thruster_backleft.writeMicroseconds(pwmBackLeft);
          thruster_sideright.writeMicroseconds(pwmSideRight-100);
          thruster_sideleft.writeMicroseconds(pwmSideLeft-100);
          break;
        case 101: //e : go up
          thruster_frontright.writeMicroseconds(pwmFrontRight-100); 
          thruster_frontleft.writeMicroseconds(pwmFrontLeft-100);
          thruster_backright.writeMicroseconds(pwmBackRight-100); 
          thruster_backleft.writeMicroseconds(pwmBackLeft-100);
          thruster_sideright.writeMicroseconds(pwmSideRight);
          thruster_sideleft.writeMicroseconds(pwmSideLeft);
          break;
        case 99: //c : submerge
          thruster_frontright.writeMicroseconds(pwmFrontRight+100); 
          thruster_frontleft.writeMicroseconds(pwmFrontLeft+100);
          thruster_backright.writeMicroseconds(pwmBackRight+100); 
          thruster_backleft.writeMicroseconds(pwmBackLeft+100);
          thruster_sideright.writeMicroseconds(pwmSideRight);
          thruster_sideleft.writeMicroseconds(pwmSideLeft);
          break;
        case 103: //g : the two right thrusters are on (roll)
          thruster_frontright.writeMicroseconds(pwmFrontRight+100); 
          thruster_frontleft.writeMicroseconds(pwmFrontLeft-100);
          thruster_backright.writeMicroseconds(pwmBackRight+100); 
          thruster_backleft.writeMicroseconds(pwmBackLeft-100);
          thruster_sideright.writeMicroseconds(pwmSideRight);
          thruster_sideleft.writeMicroseconds(pwmSideLeft);
          break;
        case 104: //h : the two left thrusters are on (roll)
          thruster_frontright.writeMicroseconds(pwmFrontRight-100); 
          thruster_frontleft.writeMicroseconds(pwmFrontLeft+100);
          thruster_backright.writeMicroseconds(pwmBackRight-100); 
          thruster_backleft.writeMicroseconds(pwmBackLeft+100);
          thruster_sideright.writeMicroseconds(pwmSideRight);
          thruster_sideleft.writeMicroseconds(pwmSideLeft);
          break;
        case 105: //i : the two front thrusters are on (pitch)
          thruster_frontright.writeMicroseconds(pwmFrontRight+100); 
          thruster_frontleft.writeMicroseconds(pwmFrontLeft+100);
          thruster_backright.writeMicroseconds(pwmBackRight-100); 
          thruster_backleft.writeMicroseconds(pwmBackLeft-100);
          thruster_sideright.writeMicroseconds(pwmSideRight);
          thruster_sideleft.writeMicroseconds(pwmSideLeft);
          break;
        case 106: //j : the two back thrusters are on (pitch)
          thruster_frontright.writeMicroseconds(pwmFrontRight-100); 
          thruster_frontleft.writeMicroseconds(pwmFrontLeft-100);
          thruster_backright.writeMicroseconds(pwmBackRight+100); 
          thruster_backleft.writeMicroseconds(pwmBackLeft+100);
          thruster_sideright.writeMicroseconds(pwmSideRight);
          thruster_sideleft.writeMicroseconds(pwmSideLeft);
          break;
        case 111: //o : shut off all motors
          thruster_frontright.writeMicroseconds(pwmFrontRight); 
          thruster_frontleft.writeMicroseconds(pwmFrontLeft);
          thruster_backright.writeMicroseconds(pwmBackRight); 
          thruster_backleft.writeMicroseconds(pwmBackLeft);
          thruster_sideright.writeMicroseconds(pwmSideRight);
          thruster_sideleft.writeMicroseconds(pwmSideLeft);
          break;
        default:
          thruster_frontright.writeMicroseconds(pwmFrontRight); 
          thruster_frontleft.writeMicroseconds(pwmFrontLeft);
          thruster_backright.writeMicroseconds(pwmBackRight); 
          thruster_backleft.writeMicroseconds(pwmBackLeft);
          thruster_sideright.writeMicroseconds(pwmSideRight);
          thruster_sideleft.writeMicroseconds(pwmSideLeft);
          break;
       }
  }

  else{

          thruster_frontright.writeMicroseconds(pwmFrontRight); 
          thruster_frontleft.writeMicroseconds(pwmFrontLeft);
          thruster_backright.writeMicroseconds(pwmBackRight); 
          thruster_backleft.writeMicroseconds(pwmBackLeft);
          //thruster_sideright.writeMicroseconds(pwmSideRight);
          //thruster_sideleft.writeMicroseconds(pwmSideLeft);
    
  }

//////////////////////////////////////////////////////


//Store errors for next loop

previous_errorY = errorY; 
previous_errorX = errorX;
previous_errorZ = errorZ;
previous_depth_error = depth_error;

//Serial.println(current_depth);

//Serial.print(z_angle);
//Serial.print(' ');
//Serial.print(x_angle);
//Serial.print(' ');
//Serial.println(y_angle);

}

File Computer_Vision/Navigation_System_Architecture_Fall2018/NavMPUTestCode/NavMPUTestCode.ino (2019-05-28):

    // verify connection
    Serial.println(F("Testing device connections..."));
    Serial.println(mpu.testConnection() ? F("MPU6050 connection successful") : F("MPU6050 connection failed"));

    // wait for ready
    Serial.println(F("\nSend any character to begin DMP programming and demo: "));
    while (Serial.available() && Serial.read()); // empty buffer
    while (!Serial.available());                 // wait for data
    while (Serial.available() && Serial.read()); // empty buffer again

    // load and configure the DMP
    Serial.println(F("Initializing DMP..."));
    devStatus = mpu.dmpInitialize();

    // supply your own gyro offsets here, scaled for min sensitivity
    mpu.setXGyroOffset(220);
    mpu.setYGyroOffset(76);
    mpu.setZGyroOffset(-85);
    mpu.setZAccelOffset(1788); // 1688 factory default for my test chip

    // make sure it worked (returns 0 if so)
    if (devStatus == 0) {
        // turn on the DMP, now that it's ready
        Serial.println(F("Enabling DMP..."));
        mpu.setDMPEnabled(true);

        // enable Arduino interrupt detection
        Serial.println(F("Enabling interrupt detection (Arduino external interrupt 0)..."));
        attachInterrupt(0, dmpDataReady, RISING);
        mpuIntStatus = mpu.getIntStatus();

        // set our DMP Ready flag so the main loop() function knows it's okay to use it
        Serial.println(F("DMP ready! Waiting for first interrupt..."));
        dmpReady = true;

        // get expected DMP packet size for later comparison
        packetSize = mpu.dmpGetFIFOPacketSize();
    } else {
        // ERROR!
        // 1 = initial memory load failed
        // 2 = DMP configuration updates failed
        // (if it's going to break, usually the code will be 1)
        Serial.print(F("DMP Initialization failed (code "));
        Serial.print(devStatus);
        Serial.println(F(")"));
    }

    // configure LED for output
    pinMode(LED_PIN, OUTPUT);
}



// ================================================================
// ===                    MAIN PROGRAM LOOP                     ===
// ================================================================

void loop() {
    // if programming failed, don't try to do anything
    if (!dmpReady) return;

    // wait for MPU interrupt or extra packet(s) available
    while (!mpuInterrupt && fifoCount < packetSize) {
        // other program behavior stuff here
        // .
        // if you are really paranoid you can frequently test in between other
        // stuff to see if mpuInterrupt is true, and if so, "break;" from the
        // while() loop to immediately process the MPU data
        // .
    }

    // reset interrupt flag and get INT_STATUS byte
    mpuInterrupt = false;
    mpuIntStatus = mpu.getIntStatus();

    // get current FIFO count
    fifoCount = mpu.getFIFOCount();

    // check for overflow (this should never happen unless our code is too inefficient)
    if ((mpuIntStatus & 0x10) || fifoCount == 1024) {
        // reset so we can continue cleanly
        mpu.resetFIFO();
        Serial.println(F("FIFO overflow!"));

    // otherwise, check for DMP data ready interrupt (this should happen frequently)
    } else if (mpuIntStatus & 0x02) {
        // wait for correct available data length, should be a VERY short wait
        while (fifoCount < packetSize) fifoCount = mpu.getFIFOCount();

        // read a packet from FIFO
        mpu.getFIFOBytes(fifoBuffer, packetSize);
        
        // track FIFO count here in case there is > 1 packet available
        // (this lets us immediately read more without waiting for an interrupt)
        fifoCount -= packetSize;

            // display Euler angles in degrees
            mpu.dmpGetQuaternion(&q, fifoBuffer);
            mpu.dmpGetGravity(&gravity, &q);
            mpu.dmpGetYawPitchRoll(ypr, &q, &gravity);
            Serial.print("ypr\t");
            Serial.print(ypr[0] * 180/M_PI);
            Serial.print("\t");
            Serial.print(ypr[1] * 180/M_PI);
            Serial.print("\t");
            Serial.println(ypr[2] * 180/M_PI);

            // display initial world-frame acceleration, adjusted to remove gravity
            // and rotated based on known orientation from quaternion
            mpu.dmpGetQuaternion(&q, fifoBuffer);
            mpu.dmpGetAccel(&aa, fifoBuffer);
            mpu.dmpGetGravity(&gravity, &q);
            mpu.dmpGetLinearAccel(&aaReal, &aa, &gravity);
            mpu.dmpGetLinearAccelInWorld(&aaWorld, &aaReal, &q);
            Serial.print("aworld\t");
            Serial.print(aaWorld.x);
            Serial.print("\t");
            Serial.print(aaWorld.y);
            Serial.print("\t");
            Serial.println(aaWorld.z);
    
        // blink LED to indicate activity
        blinkState = !blinkState;
        digitalWrite(LED_PIN, blinkState);
    }
}

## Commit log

2019-05-31 Create Robosub 2018-2019 Assembly_REV 053019
2019-05-31 Rename Mechanical/Robosub 2018-2019 Assembly_REV 053019 to Robosub 2018-2019 Assembly_REV 053019
2019-05-31 Rename Robosub 2018-2019 Assembly_REV 053019 to Mechanical/Robosub 2018-2019 Assembly_REV 053019
